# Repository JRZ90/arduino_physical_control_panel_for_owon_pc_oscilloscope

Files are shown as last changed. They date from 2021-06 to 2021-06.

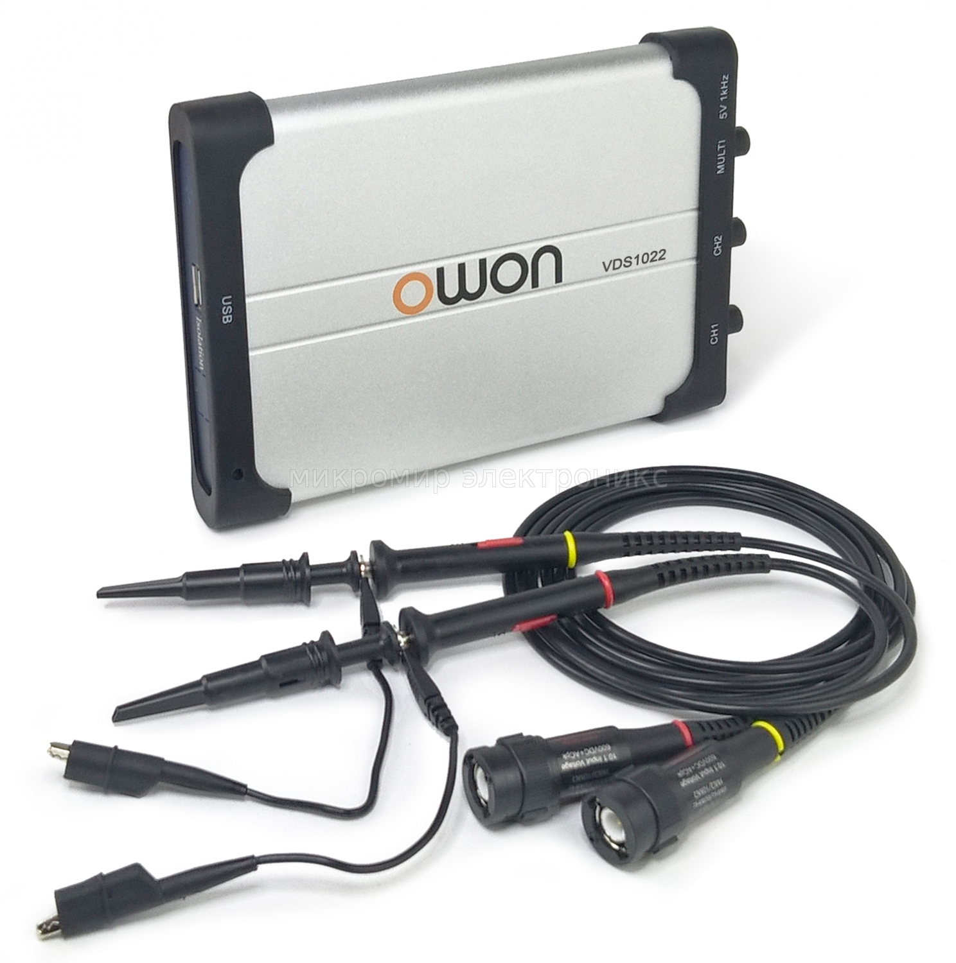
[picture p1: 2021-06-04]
jpg/owon_VDS_1022.jpg

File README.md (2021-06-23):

This is a physical control panel for owon pc oscilloscopes, but can be used with any other brand and codel. The working principle is very simple, the software has some keyboard shortcuts for control some actions such the amplitude and time scale. When you press a button or turn the knob the arduino send a signal to python and this is who send a keystroke to the oscilloscope software emulating the keyboard.

## Requirements
### Hardware
* Arduino board with USB connection, any Arduino compatible board with CH340 chip work just fine, no HID capabilities required.
* One of the pcbs for mount the components and the arduino.

### Environment
* Windows
* Python 3
* Arduino

* The PCB (ver_mini) can be easily done  with the toner transfer mnethod. But the extended version is much more complex and was designed to be done by a pcb manufacturer such as JLCPCB or PCBWAY.
* All the components are very inexpensive and easy to find. Each PCB has a Bom file with all the required components.

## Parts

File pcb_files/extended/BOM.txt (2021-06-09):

Qty 	Value              	Device             	Parts                                             		Description
4                      		LED 5mm             	LED1, LED2, LED3, LED4                            	LED                                                           
12  	10K                	RESISTOR        	R1, R2, R3, R4, R5, R6, R7, R8, R9, R10, R13, R14 	RESISTOR 1/4W
4   	330                	RESISTOR        	R11, R12, R15, R16                                		RESISTOR 1/4W
1   	ARDUINO-NANO-3.0   	ARDUINO-NANO-3.0   	M100                                              		Arduino Nano 3.0 and compatible devices                       
2   	ROTARTY_ENCODER    	ROTARTY_ENCODER    	SW3, SW4                                          		Simple no LED rotary encoder                                  
6   	TACTILE-SWITCH-PTH 	TACTILE-SWITCH-PTH 	SW1, SW2, SW5, SW6, SW7, SW8                      	Tactile Switch 4 Pins, SPST NO

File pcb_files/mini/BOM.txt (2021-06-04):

Qty 	Value              		Device             		Parts                  		Description              
3      	                		LED 5mm             		LED1, LED2, LED3       		LED                                                           
6   	10K                		RESISTOR        		R1, R2, R3, R7, R8, R9 		RESISTOR 1/4W
3   	330                		RESISTOR        		R4, R5, R6             		RESISTOR 1/4W
1   	ARDUINO-NANO-3.0   		ARDUINO-NANO-3.0   		M1                     		Arduino Nano 3.0 and compatible devices
1   	ROTARTY_ENCODER    		ROTARTY_ENCODER    		SW1                    		Simple no LED rotary encoder
3   	TACTILE-SWITCH 			TACTILE-SWITCH-PTH 		SW2, SW3, SW4          		Tactile Switch 4 Pins, SPST NO

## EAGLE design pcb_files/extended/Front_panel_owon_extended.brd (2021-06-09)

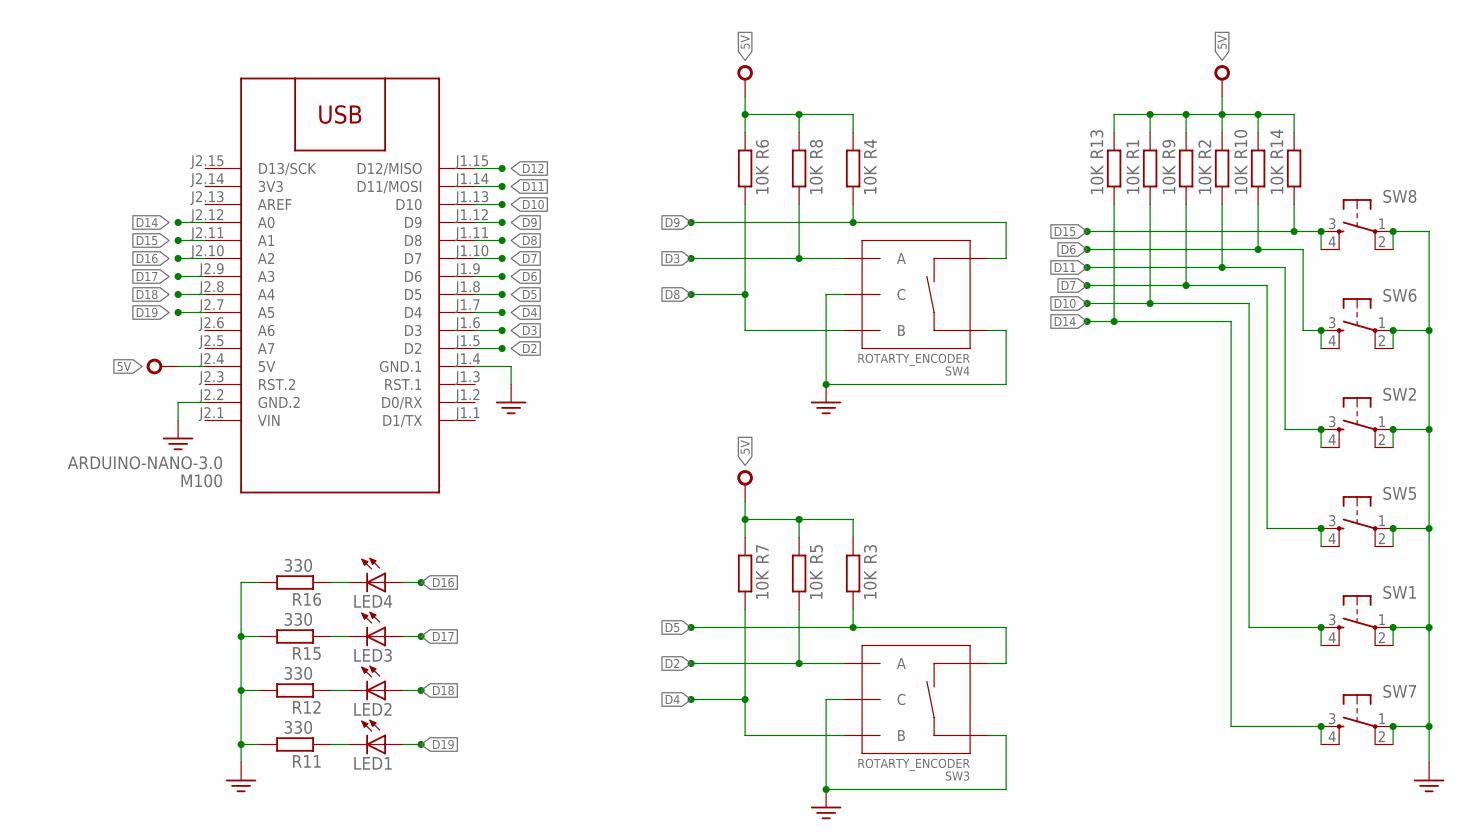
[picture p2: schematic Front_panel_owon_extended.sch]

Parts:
LED1, LED2, LED3, LED4: LED5MM
M100: ARDUINO-NANO-3.0
R1, R2, R3, R4, R5, R6, R7, R8, R9, R10, R13, R14: 10K; 0204/7
R11, R12, R15, R16: 330; 0204/7
SW1, SW2, SW5, SW6, SW7, SW8: TACTILE-SWITCH-PTH; TAC-SWITCH-PTH
SW3, SW4: ROTARTY_ENCODER; ROTARY_ENC_PLAIN

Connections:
3V3: M100.J2.14 (3V3)
5V: M100.J2.4 (5V), R1.2, R2.2, R3.2, R4.2, R5.2, R6.2, R7.2, R8.2, R9.2, R10.2, R13.2, R14.2
D2: M100.J1.5 (D2), R5.1, SW3.A
D3: M100.J1.6 (D3), R8.1, SW4.A
D4: M100.J1.7 (D4), R7.1, SW3.B
D5: M100.J1.8 (D5), R3.1, SW3.SW-
D6: M100.J1.9 (D6), R10.1, SW6.3, SW6.4
D7: M100.J1.10 (D7), R9.1, SW5.3, SW5.4
D8: M100.J1.11 (D8), R6.1, SW4.B
D9: M100.J1.12 (D9), R4.1, SW4.SW-
D10: M100.J1.13 (D10), R1.1, SW1.3, SW1.4
D11: M100.J1.14 (D11/MOSI), R2.1, SW2.3, SW2.4
D12: M100.J1.15 (D12/MISO)
D14: M100.J2.12 (A0), R13.1, SW7.3, SW7.4
D15: M100.J2.11 (A1), R14.1, SW8.3, SW8.4
D16: LED4.A, M100.J2.10 (A2)
D17: LED3.A, M100.J2.9 (A3)
D18: LED2.A, M100.J2.8 (A4)
D19: LED1.A, M100.J2.7 (A5)
GND: M100.J1.4 (GND.1), M100.J2.2 (GND.2), R11.2, R12.2, R15.2, R16.2, SW1.1, SW1.2, SW2.1, SW2.2, SW3.C, SW3.SW+, SW4.C, SW4.SW+, SW5.1, SW5.2, SW6.1, SW6.2, SW7.1, SW7.2, SW8.1, SW8.2
unnamed: LED1.K (C), R11.1
unnamed: LED2.K (C), R12.1
unnamed: LED3.K (C), R15.1
unnamed: LED4.K (C), R16.1
VIN: M100.J2.1 (VIN)

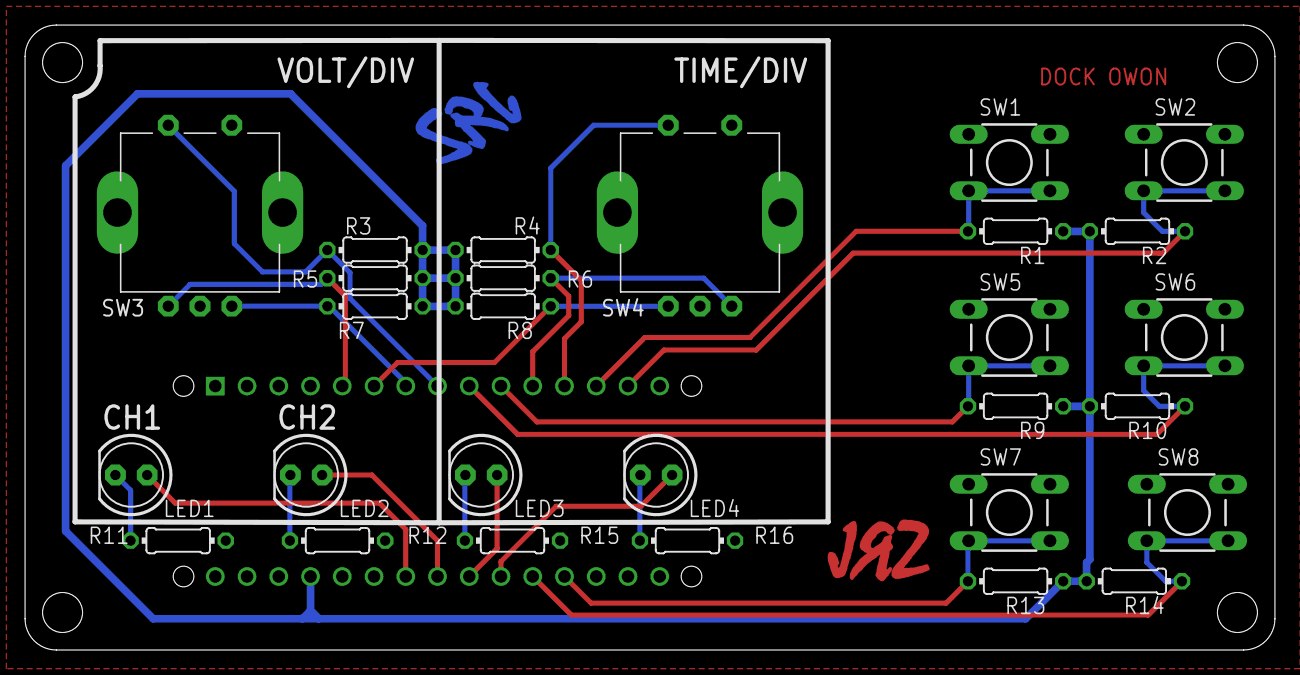
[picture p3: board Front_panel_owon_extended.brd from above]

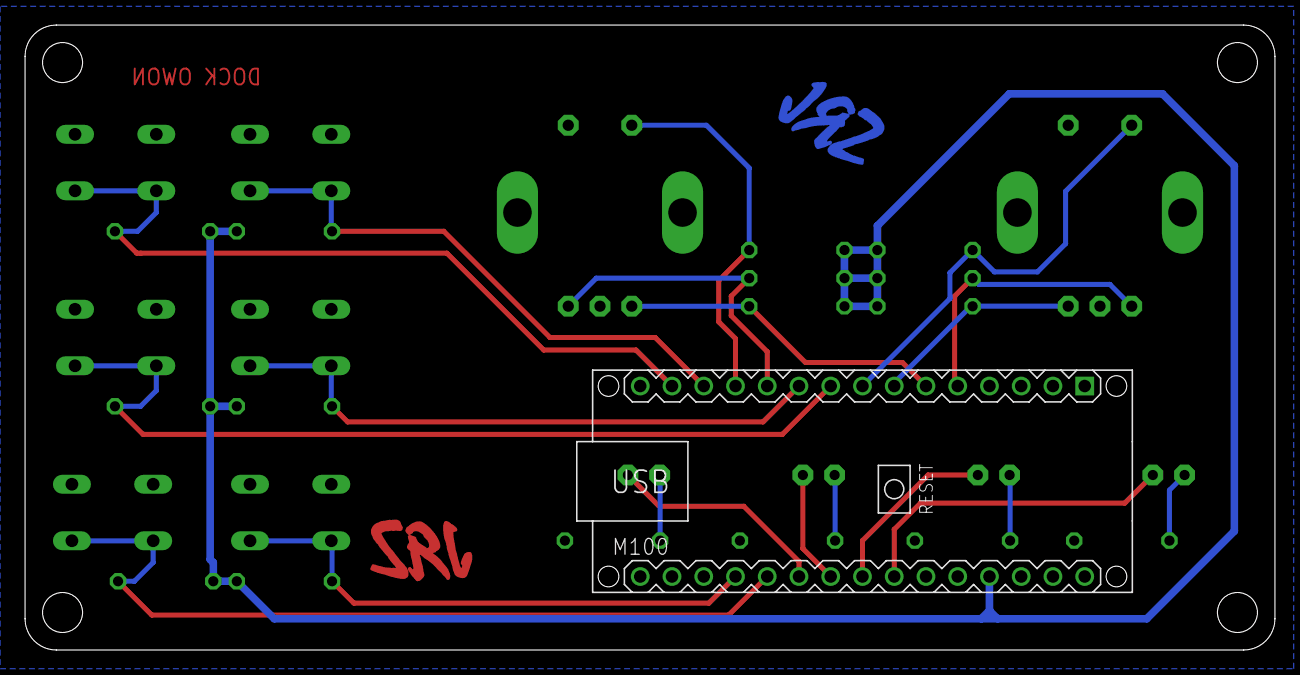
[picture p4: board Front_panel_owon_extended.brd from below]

Board: 2 copper layers, 100.0 x 50.0 mm, 31 parts (2 on the bottom side), 22 nets.

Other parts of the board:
U$1, U$3: LOGO_B

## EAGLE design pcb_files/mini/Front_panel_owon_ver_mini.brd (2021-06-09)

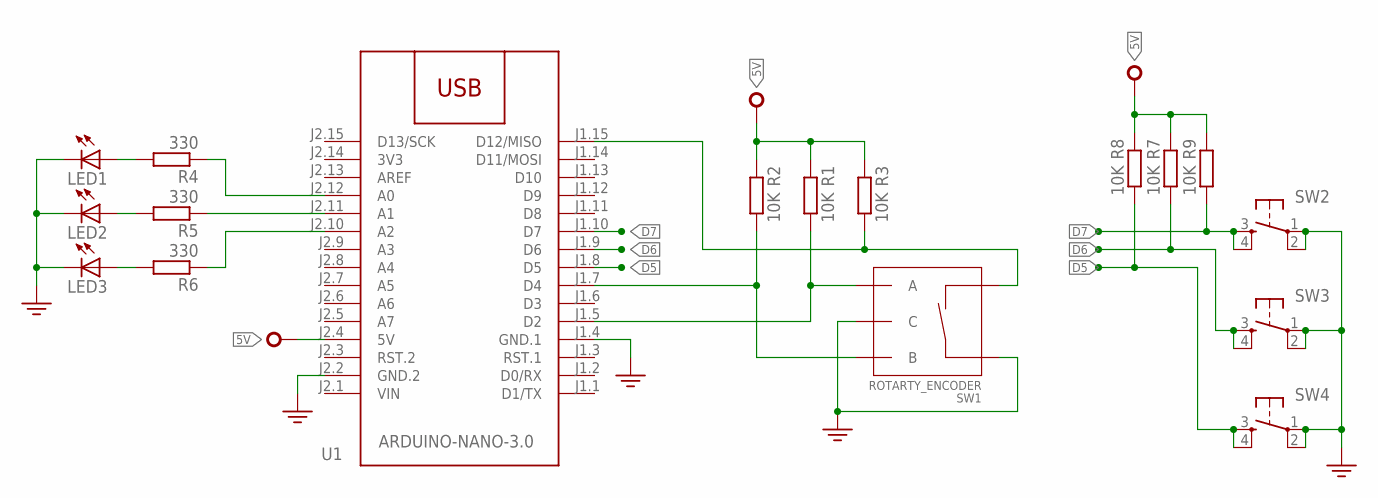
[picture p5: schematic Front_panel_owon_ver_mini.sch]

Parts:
LED1, LED2, LED3: LED5MM
R1, R2, R3, R7, R8, R9: 10K; 0204/7
R4, R5, R6: 330; 0204/7
SW1: ROTARTY_ENCODER; ROTARY_ENC_PLAIN
SW2, SW3, SW4: TACTILE-SWITCH-PTH; TAC-SWITCH-PTH
U1: ARDUINO-NANO-3.0

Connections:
3V3: U1.J2.14 (3V3)
5V: R1.2, R2.2, R3.2, R7.2, R8.2, R9.2, U1.J2.4 (5V)
D2: R1.1, SW1.A, U1.J1.5 (D2)
D4: R2.1, SW1.B, U1.J1.7 (D4)
D5: R8.1, SW4.3, SW4.4, U1.J1.8 (D5)
D6: R7.1, SW3.3, SW3.4, U1.J1.9 (D6)
D7: R9.1, SW2.3, SW2.4, U1.J1.10 (D7)
D12: R3.1, SW1.SW-, U1.J1.15 (D12/MISO)
GND: LED1.K (C), LED2.K (C), LED3.K (C), SW1.C, SW1.SW+, SW2.1, SW2.2, SW3.1, SW3.2, SW4.1, SW4.2, U1.J1.4 (GND.1), U1.J2.2 (GND.2)
unnamed: R5.1, U1.J2.11 (A1)
unnamed: LED1.A, R4.2
unnamed: LED2.A, R5.2
unnamed: LED3.A, R6.2
unnamed: R4.1, U1.J2.12 (A0)
unnamed: R6.1, U1.J2.10 (A2)
VIN: U1.J2.1 (VIN)

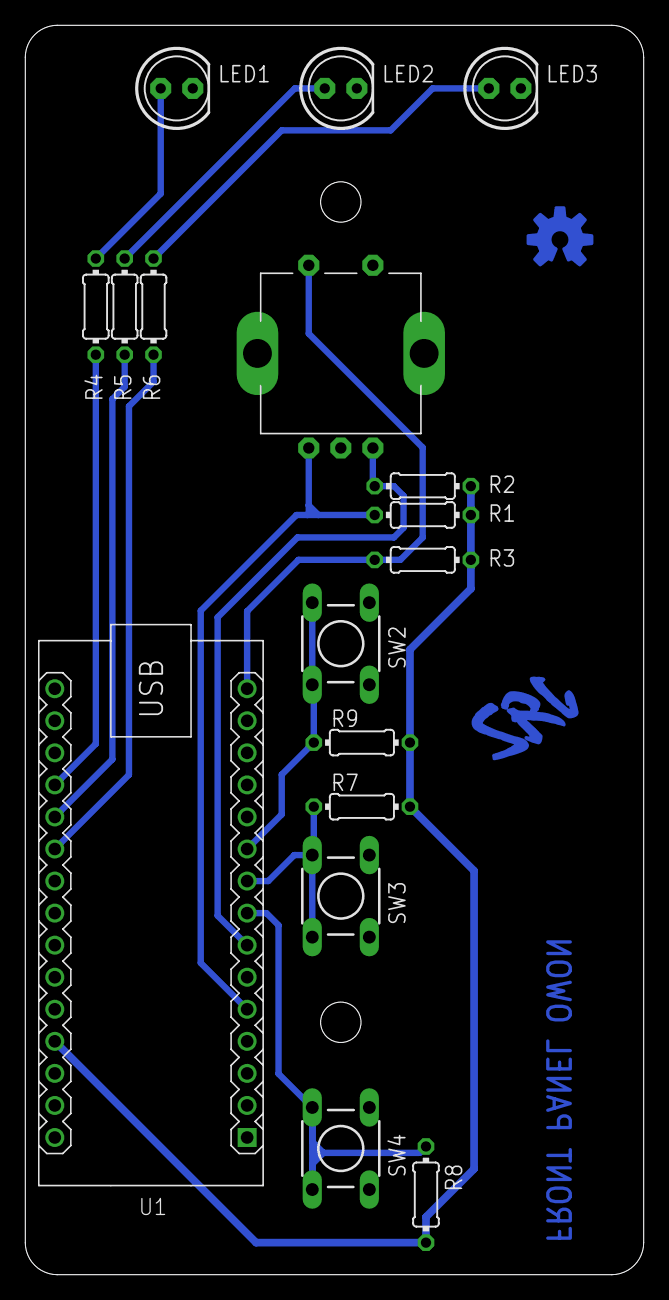
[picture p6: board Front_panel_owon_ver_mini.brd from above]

Board: 2 copper layers, 49.0 x 99.0 mm, 20 parts (1 on the bottom side), 14 nets.

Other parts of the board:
U$1: LOGO_B
U$2: OSHWLOGO_TOP_0.2
U$3: OSHWLOGO_TOL_0.2

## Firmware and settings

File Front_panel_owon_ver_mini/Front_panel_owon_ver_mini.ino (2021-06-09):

int A = 2;                       //Variable A a pin digital 2 (DT en modulo)
int B = 4;                      //Variable B a pin digital 4 (CLK en modulo)
int ANTERIOR = 50;             //Almacena valor anterior de la variable POSICION
volatile int POSICION = 50;   //Variable POSICION con valor inicial de 50 y definida
//                           //Como global al ser usada en loop e ISR (encoder)

const int PulsadorEnc = 12;                //Pin al cual se conecta el pulsador del encoder
int estado = 1;                           //Contador: variable que acumula el numero de pulsaciones
int estadoPulsadorEnc = 0;               //Variable que almacena el estado actual del pulsador
int estadoAnteriorPulsadorEnc = 0;      //Variable que almacena el estado anterior del pulsador
///

const int PulsadorUno = 7;
const int PulsadorDos = 6;
const int PulsadorTres = 8;

int estadoPulsadorUno = 0;
int estadoAnteriorPulsadorUno = 0;
int estadoPulsadorDos = 0;
int estadoAnteriorPulsadorDos = 0;
int estadoPulsadorTres = 0;
int estadoAnteriorPulsadorTres = 0;
///
int ledCh1 = 14;
int ledCh2 = 15;
int ledBaseTiempo = 16;

void setup() {
  pinMode(A, INPUT);                   //A como entrada
  pinMode(B, INPUT);                  //B como entrada
  pinMode(PulsadorEnc, INPUT);       //Inicializa el pin del pulsador como entrada
  Serial.begin(9600);               //Inicializa la comunicación Serie
  pinMode(16, OUTPUT);             //Declaramos el pin 16 como salida
  pinMode(15, OUTPUT);            //Declaramos el pin 15 como salida
  pinMode(14, OUTPUT);           //Declaramos el pin 14 como salida
  pinMode(12, INPUT);           //Declaramos el pin 12 como entrada
  pinMode(7, INPUT);           //Declaramos el pin 7 como entrada
  pinMode(6, INPUT);          //Declaramos el pin 6 como entrada
  pinMode(5, INPUT);         //Declaramos el pin 5 como entrada

  digitalWrite(13, HIGH);
  digitalWrite(14, HIGH);
  digitalWrite(15, HIGH);
  delay(500);
  digitalWrite(13, LOW);
  digitalWrite(14, LOW);
  digitalWrite(15, LOW);

  Serial.println("102");  //Imprime en monitor serial 102 indicando a python que esta listo

  attachInterrupt(digitalPinToInterrupt(A), encoder, LOW);  //Interrupcion sobre pin A con
  //                                                       //Funcion ISR encoder y modo LOW
  attachInterrupt(digitalPinToInterrupt(B), encoder, LOW);
}

void loop() {
  /////////////////////////////Encoder////////////////////////////////

  if (POSICION != ANTERIOR) {    //Si el valor de POSICION es distinto de ANTERIOR
    Serial.println(POSICION);   //Imprime valor de POSICION
    delay(50);
    POSICION = 50;
    ANTERIOR = POSICION ;    //Asigna a ANTERIOR el valor actualizado de POSICION
  }

  /////////////////////////////Pulsador encoder///////////////////////

  estadoPulsadorEnc = digitalRead(PulsadorEnc);          //Se lee y almacena el estado del pulsador
  if (estadoPulsadorEnc != estadoAnteriorPulsadorEnc) { //Se compara la variable estadoPulsadorEnc
    //                                                 //Con su valor anterior
    delay(200);
    estado = 1 + estado;                             //Pasó de un estado OFF a ON
    Serial.println(estado + 100);                   //Manda un código numerico a python para ejecutar
  }//                                              //la tarea asignada

  ///////////////---------Estados---------///////////////

  if (estado == 1) {                    //si el estado es 1
    delay(40);
    digitalWrite(ledCh1, HIGH);       //se enciende el led del canal 1
  }
  else {                            //si el estado es 0
    digitalWrite(ledCh1, LOW);     //se apaga el led
  }

  /////////////////////////////////////////////

  if (estado == 2) {
    delay(40);
    digitalWrite(ledCh2, HIGH);
  }
  else {
    digitalWrite(ledCh2, LOW);
  }

  /////////////////////////////////////////////

  if (estado == 3)  {
    delay(40);
    digitalWrite(ledBaseTiempo, HIGH);
  }
  else {
    digitalWrite(ledBaseTiempo, LOW);
  }

  if (estado > 3) {         //si estado es mayor que 3 reinicia la variable a 1
    (estado = 1);
  }

  //////////////////////////////////Pulsadores/////////////////////////////////////

  estadoPulsadorUno = digitalRead(PulsadorUno);             //Se lee y almacena el estado del pulsadorUno
  if (estadoPulsadorUno != estadoAnteriorPulsadorUno) {    //Se compara la variable estadoPulsadorUno
    //                                                    //con su valor anterior
    delay(100);
    Serial.println(1);                                  //Manda un código numerico a python para ejecutar
  }//                                                  //la tarea asignada

  estadoPulsadorDos = digitalRead(PulsadorDos);
  if (estadoPulsadorDos != estadoAnteriorPulsadorDos) {
    delay(100);
    Serial.println(2);
  }

  estadoPulsadorTres = digitalRead(PulsadorTres);
  if (estadoPulsadorTres != estadoAnteriorPulsadorTres) {
    delay(100);
    Serial.println(3);
  }

}

void encoder()  {
  static unsigned long ultimaInterrupcion = 0;            //Variable static con ultimo valor de
  //                                                     //Tiempo de interrupcion
  unsigned long tiempoInterrupcion = millis();          //Variable almacena valor de func. millis

  if (tiempoInterrupcion - ultimaInterrupcion > 5) {  //Rutina antirebote desestima
    //                                               //Pulsos menores a 5 mseg.
    if (digitalRead(B) == HIGH)  //Si B es HIGH, sentido horario
    {
      POSICION++ ;             //Incrementa POSICION en 1
    }
    else {                   //Si B es LOW, senti anti horario
      POSICION-- ;          //Decrementa POSICION en 1
    }

    POSICION = min(100, max(0, POSICION));      //Establece limite inferior de 0 y
    //                                         //Superior de 100 para POSICION
    ultimaInterrupcion = tiempoInterrupcion;  //Guarda valor actualizado del tiempo
  } //                                       //De la interrupcion en variable static
}

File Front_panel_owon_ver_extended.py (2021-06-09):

import serial
import win32com.client as comclt

arduino = serial.Serial("COM5", 9600) # Escuchamos en el puerto COM en el que esta el 
#arduino a 9600 baudios.

selector = 0

# Este bloque de codigo recibe una cadena de caracteres que es enviada por el arduino y
# la procesa hasta dejar en limpio solo el valor que nos interesa.
while (1):
    while (arduino.inWaiting()==0):
        pass
    dato = arduino.readline() #dato = b'1\r\n'
    a = dato.splitlines()     #a = [b'1']
    b = str(a[0])             #b = b'1'
    c = b.replace("b","")     #c = '1'
    d = c.replace("'","")     #d = 1
    e = int(d) # En esta variable se guarda el valor final enviado por el arduino.
    #print(e)

#----------------------------------------------------
# Este bloque de codigo es el encargado de manejar la funcion del encoder en base al
# valor enviado por el arduino (102 o 103) 
    if e == 102:
        selector = 'ch1'
        print('Canal 1')
        
    elif e == 103:
        selector = 'ch2'
        print('Canal 2')
 
#----------------------------------------------------


    if e == 59:
        wsh= comclt.Dispatch("WScript.Shell")
        wsh.AppActivate("launcher.exe")
        wsh.SendKeys("{RIGHT}")

    if e == 61:
        wsh= comclt.Dispatch("WScript.Shell")
        wsh.AppActivate("launcher.exe")
        wsh.SendKeys("{LEFT}")


#----------------------------------------------------
    
    if selector == 'ch1':
        if e == 49:
            wsh= comclt.Dispatch("WScript.Shell")
            wsh.AppActivate("launcher.exe")
            wsh.SendKeys("A")

        if e == 51:
            wsh= comclt.Dispatch("WScript.Shell")
            wsh.AppActivate("launcher.exe")
            wsh.SendKeys("Q")
    else:
        pass

#----------------------------------------------------
    
    if selector == 'ch2':
        if e == 49:
            wsh= comclt.Dispatch("WScript.Shell")
            wsh.AppActivate("launcher.exe")
            wsh.SendKeys("S")

        if e == 51:
            wsh= comclt.Dispatch("WScript.Shell")
            wsh.AppActivate("launcher.exe")
            wsh.SendKeys("W")
    else:
        pass

#----------------------------------------------------

    if e == 1:  #SW2   >>Run/Stop<<
        wsh= comclt.Dispatch("WScript.Shell")
        wsh.AppActivate("launcher.exe")
        wsh.SendKeys("{F5}") #F5

    if e == 2:  #SW6   >>single trigger<<
        wsh= comclt.Dispatch("WScript.Shell")
        wsh.AppActivate("launcher.exe")
        wsh.SendKeys(" ") #Espacio
        

    if e == 3:  #SW8   >>AutoSet<<
        wsh= comclt.Dispatch("WScript.Shell")
        wsh.AppActivate("launcher.exe")
        wsh.SendKeys("^~") #CTRL + ENTER

#----------------------------------------------------
# Estos botones se dejan sin ninguna funcion para una posible actualizacion
# del software con mas shortcuts o tambien para agregar cualquier otro comando
# que use necesite.

    if e == 4:  #SW1
        wsh= comclt.Dispatch("WScript.Shell")
        wsh.AppActivate("launcher.exe")
        wsh.SendKeys("")

    if e == 5:  #SW5
        wsh= comclt.Dispatch("WScript.Shell")
        wsh.AppActivate("launcher.exe")
        wsh.SendKeys("")

    if e == 6:  #SW7
        wsh= comclt.Dispatch("WScript.Shell")
        wsh.AppActivate("launcher.exe")
        wsh.SendKeys("")
        
    if e == 7:  #SW4 (Pulsador encoder horizontal)
        wsh= comclt.Dispatch("WScript.Shell")
        wsh.AppActivate("launcher.exe")
        wsh.SendKeys("")

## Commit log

2021-06-04 primer commit, todo funciona bien
    [Front_panel_owon_ver_mini.brd, Front_panel_owon_ver_mini.sch]
2021-06-09 retoques, mejoras y agregados
    [Front_panel_owon_extended.brd, Front_panel_owon_extended.sch, Front_panel_owon_ver_mini.brd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]

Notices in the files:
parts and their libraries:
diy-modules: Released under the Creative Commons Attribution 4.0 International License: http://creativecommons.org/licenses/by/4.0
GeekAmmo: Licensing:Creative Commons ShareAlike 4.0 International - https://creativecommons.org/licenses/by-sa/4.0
